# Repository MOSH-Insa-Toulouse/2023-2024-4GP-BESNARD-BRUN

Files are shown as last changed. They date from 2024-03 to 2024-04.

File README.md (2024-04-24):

# 2023-2024 : Capteur low-tech Graphite (Niels Brun &amp; Paul Besnard)

## SOMMAIRE
*** 
  - [Contexte](#contexte)
  - [Livrables](#livrables)
  - [Matériel nécessaire](#matériel-nécessaire)
  - [1. Simulation électronique du capteur sous LTSpice](#simulation-électronique-du-capteur-sous-ltspice)
  - [2. Design du PCB sous KiCad](#design-du-pcb-sous-kicad)
  - [3. Code arduino](#code-arduino)
  - [4. Application android APK sous MIT App Inventor](#application-android-apk-sous-mit-app-inventor)
  - [5. Réalisation du shield](#réalisation-du-shield)
  - [6. Banc de test](#banc-de-test)
  - [7. Datasheet](#datasheet)
  - [Contact](#contact) 

*** 

## Contexte
&nbsp;&nbsp;&nbsp;&nbsp;&nbsp;&nbsp;Dans le cadre de l'UF "Du capteur au banc de test" se déroulant en 4ème année de Génie Physique de l’INSA Toulouse, nous avons développé un dispositif permettant de mesurer la contrainte. Le capteur du dispositif est basé sur l'article "Pencil Drawn Strain Gauges and Chemiresistors on Paper" (Cheng-Wei Lin*, Zhibo Zhao*, Jaemyung Kim & Jiaxing Huang). Il est simplement composé d'un bout de papier avec du graphite que l'on vient déposer à l'aide d'un crayon à papier. En déformant le papier, le nombre de particules de graphite reliées, composant le crayon à papier déposé sur le papier, varie en fonction du type de déformation. Ce système granulaire subit une modification de résistance et de conductance. Grâce à cela, on  pourra remonter à la déformation tel une jauge de contrainte traditionnel. \
&nbsp;&nbsp;&nbsp;&nbsp;&nbsp;&nbsp;L'objectif est donc de pouvoir réaliser un dispositif permettant la mesure de déformation à partir d'un capteur low-tech. En passant par différentes étapes : simulations électroniques, design du PCB, code arduino et réalisation de datasheet.

## Livrables
- Un Shield PCB relié à une carte arduino UNO avec différents composants : un capteur graphite, un amplificateur transimpédance et un module bluetooth. Il peut également avoir un écran OLED, un flex sensor commercial, un potentiomètre digital, encodeur rotatoire ou des boutons.
- Un code arduino qui gère les différents composants cités précédemments (mesures de contraintes, échanges bluetooth et OLED, potentiomètre digital et boutons)
- Une application Android (sous MIT App Inventor) interfaçant le PCB et le code arduino.
- Un code arduino réalisant les essais de banc de test sur les mesures de contraintes.
- Une datasheet sur le capteur de contrainte.

&nbsp;&nbsp;&nbsp;&nbsp;&nbsp;&nbsp;Nous avons opté pour l'ajout d'un écran OLED, du flex sensor commercial, du potentiomètre digital. Egalement, nous avons choisi l'implémentation de 3 boutons plutôt que de l'encodeur rotatoire.

## Matériel nécessaire
Pour réaliser notre dispositif électronique, voici la liste des composants nécessaires :

- Résistances : 1 de 1 $k\ohm$, 1 de $10k\ohm$, 2 de $100k\ohm$ pour l'amplificateur transimpédance. 3 de $10k\ohm$ pour les boutons (peuvent être éviter en utilisant les résistances internes de l'arduino) et 1 de $47k\ohm$ pour le flex sensor.
- Capacités : 3 de 100 nF, 1 de 1 uF
- Arduino Uno
- Amplificateur opérationnel LTC1050
- Potentiomètre digital MCP41050
- Module Bluetooth HC05
- Ecran OLED 128x64
- Flex Sensor
- 3 boutons

## Simulation électronique du capteur sous LTSpice
&nbsp;&nbsp;&nbsp;&nbsp;&nbsp;&nbsp;Notre capteur de graphite possède une résistance variable de l'ordre du gigaohm. Le courant alors généré lorsque l'on applique une tension de 5V aux bornes du capteur est très faible (de l'ordre de la dizaine de nanoampères). Ainsi, pour récupérer et pouvoir analyser ce signal, nous devons l'amplifier. C'est pourquoi nous avons utilisé un montage transimpédance constitué d'un amplificateur opérationnel (AOP) pour fournir un signal en tension suffisant au convertisseur analogique-numérique (ADC) d'une carte Arduino UNO. \
Nous avons testé ce montage sur le logiciel LTspice basé sur [ce schéma](https://github.com/MOSH-Insa-Toulouse/2023-2024-4GP-BESNARD-BRUN/blob/main/Images/LTspice/schema_suggere.png) . Voici son schéma :

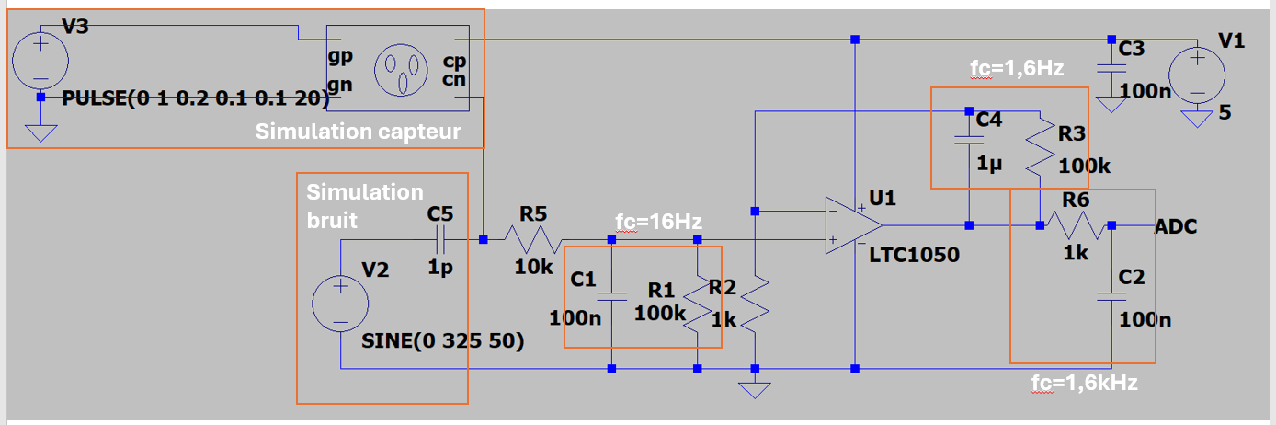
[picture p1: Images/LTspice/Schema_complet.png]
capteur_graphite


&nbsp;&nbsp;&nbsp;&nbsp;&nbsp;&nbsp;Concernant le choix de notre AOP, celui-ci devait être capable d'accepter en entrée un très faible courant. Il doit également avoir un offset de tension très faible afin de ne pas fausser les valeurs de tension transmises à l'ADC qui seront ensuite analysées. C'est pourquoi nous avons choisi le LTC 1050.
A ce circuit amplificateur, nous avons ajouté trois filtres pour notre signal :

- à l'entrée, un filtre passe-bas passif (R1,C1) de fréquence de coupure de 16 Hz. Il permet de filtrer les bruits en courant sur le signal d'entrée
- un autre filtre passe bas de fréquence de coupure de 1.6 Hz (R3,C4) couplé à l'AOP. Ce filtre actif permet de filtrer la composante du bruit à 50 Hz provenant du réseau électrique
- à la sortie de l'amplificateur, un dernier filtre (R6,C2) de 1.6 kHz permet de retirer le bruit créé en cours de traitement (bruits des alimentation, de l'horloge etc...)

&nbsp;&nbsp;&nbsp;&nbsp;&nbsp;&nbsp;Egalement, nous avons placé la capacité C3 de sorte à ce qu'elle filtre le bruit de l'alimentation. Aussi, la résistance R5 en entrée protège l'AOP contre les décharges électrostatiques en plus de formé avec la capacité C1 un filtre pour les bruits en tension. Enfin, la résistance R2 sera remplacé plus tard par un potentiomètre digital. Cela nous permettra de régler le gain de notre AOP en fonction de nos besoins.

Nous avons donc testé notre circuit afin de savoir si nos filtres seraient efficients :

Voici la réponse de notre circuit pour vérfier que le capteur soit correctement amplifié : 

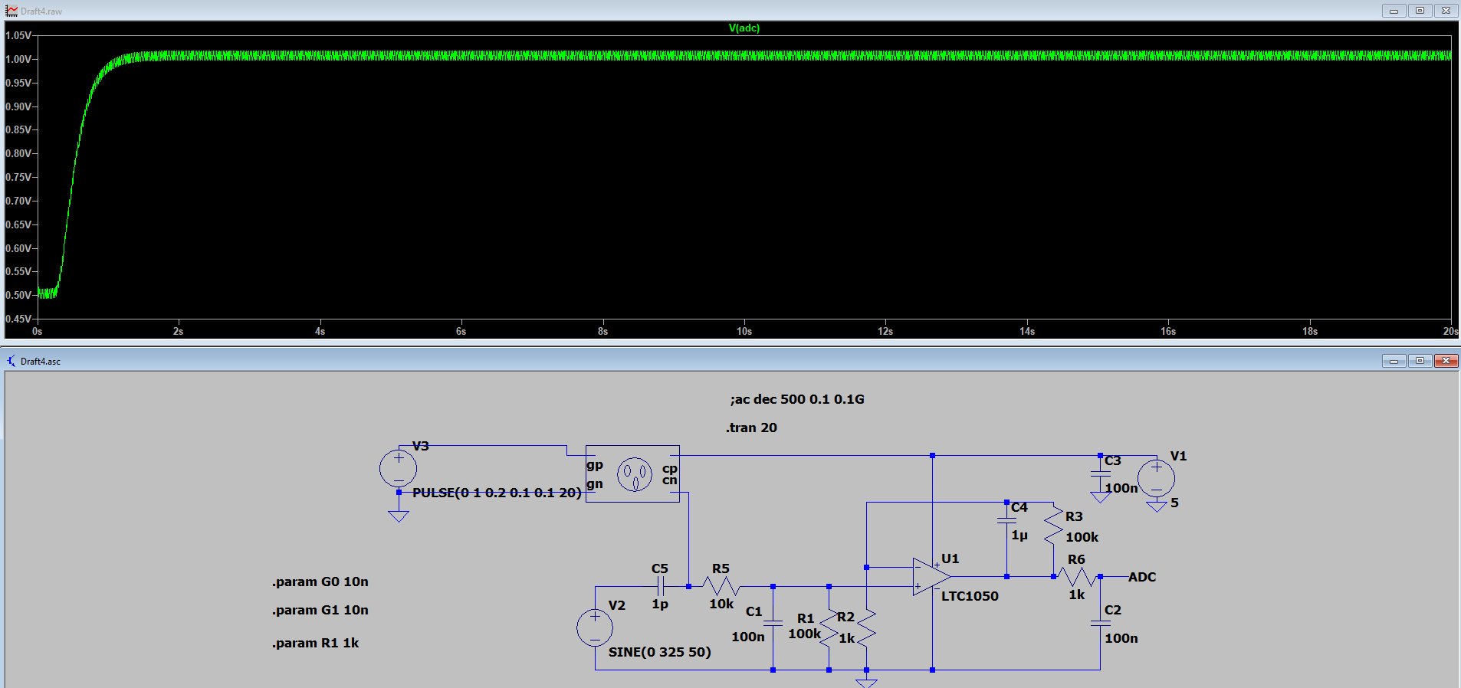
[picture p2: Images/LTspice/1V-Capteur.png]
Test_En_Transient

	
Le signal est amplifié à 1V donc l'arduino UNO pourra le mesurer.

Enfin, voici la réponse lorsque l'on simule un courant alternatif pour vérifier que le bruit est bien filtré.

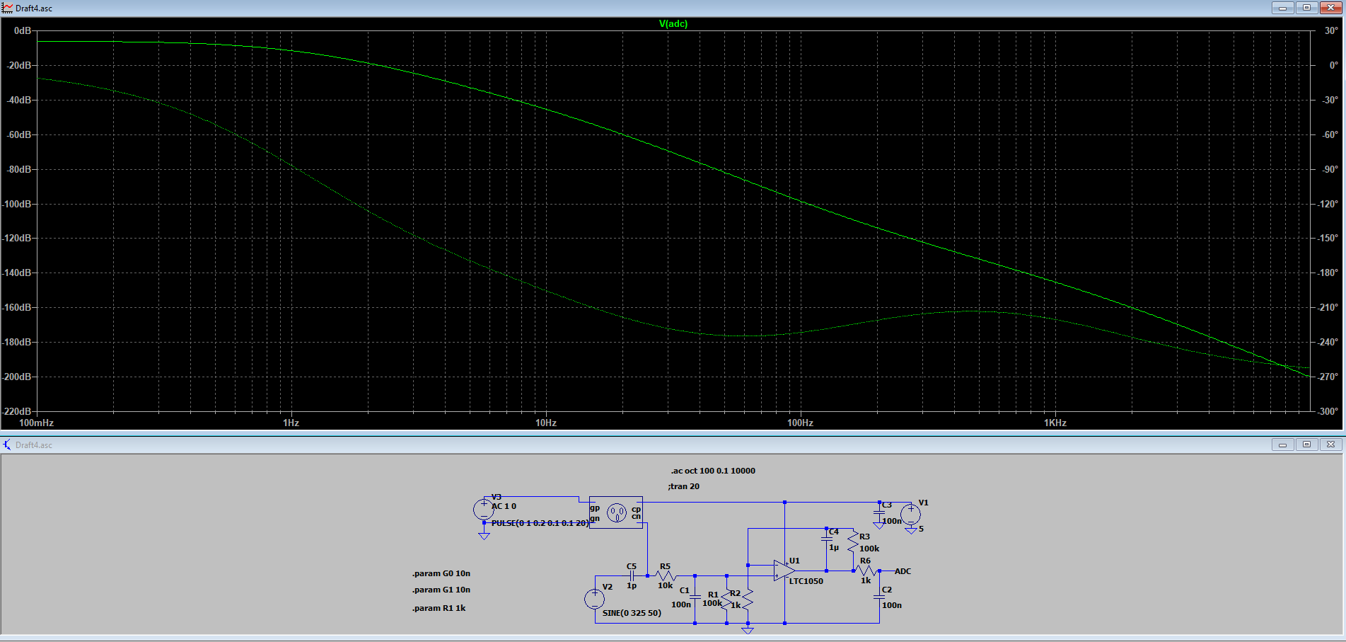
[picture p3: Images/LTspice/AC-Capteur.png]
Test_En_AC


On remarque que le bruit est bien atténué, à 50Hz, il est atténue d'environ 72 dB.

## Design du PCB sous KiCad

&nbsp;&nbsp;&nbsp;&nbsp;&nbsp;&nbsp;Afin de réaliser notre PCB, nous avons reproduit le circuit précédent sur Kicad 7.0. 
Nous avons remplacé la résistance R2 par un potentiomètre numérique afin de pouvoir faire varier le gain de notre AOP. Egalement, nous avons rajouté divers composants afin de pouvoir mesurer efficacement notre capteur graphite et comparé les résultats obtenus :
- un flexsensor servant de témoin, afin de pouvoir comparer nos mesures avec celle du capteur en graphite
- un module bluetooth HC-05 afin de pouvoir communiquer avec notre circuit depuis notre téléphone depuis une application mobile que nous coderons nous-même. 
- un écran OLED ainsi que trois boutons poussoirs afin de pouvoir visualiser le résultats de nos mesures et pouvoir naviguer simplement dans les différents menus permettant diverses mesures

&nbsp;&nbsp;&nbsp;&nbsp;&nbsp;&nbsp;Tous nos composants seront installés sur un shield d'Arduino UNO. 

&nbsp;&nbsp;&nbsp;&nbsp;&nbsp;&nbsp;Nous avons commencé par réaliser les symboles des différents composants et reproduire le schéma électrique complet sur Kicad. Voici le schéma électrique de l'ensemble de notre montage :

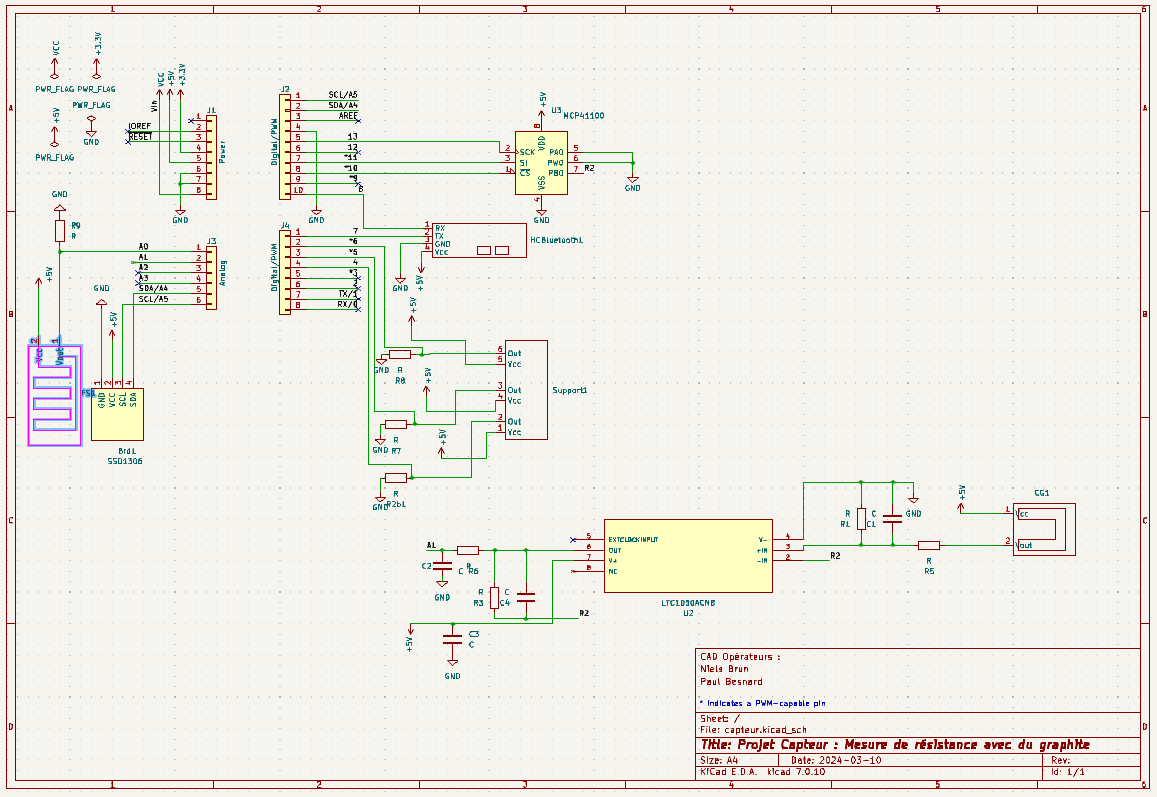
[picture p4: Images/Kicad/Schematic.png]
Schema_Kicad


&nbsp;&nbsp;&nbsp;&nbsp;&nbsp;&nbsp;Nous avons par la suite réalisé les empreintes de nos composants afin de les placer sur notre PCB. Notre difficulté principale a été de placer les composants de sorte qu'il n'y ait pas de via, notamment pour le GND. Voici le résultat final :

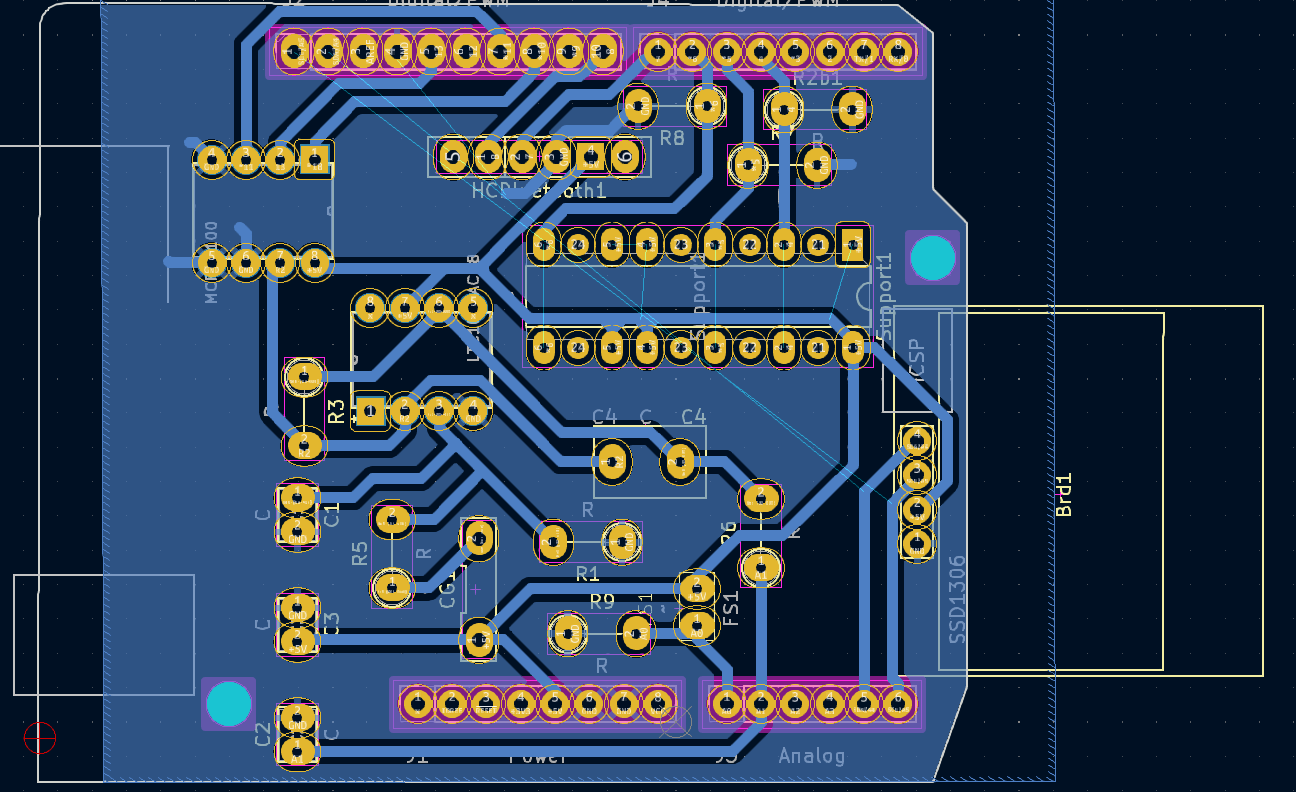
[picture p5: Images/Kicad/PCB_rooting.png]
PCB_Kicad


&nbsp;&nbsp;&nbsp;&nbsp;&nbsp;&nbsp;Et voici le rendu 3D que nous obtenu avec ces routages : 

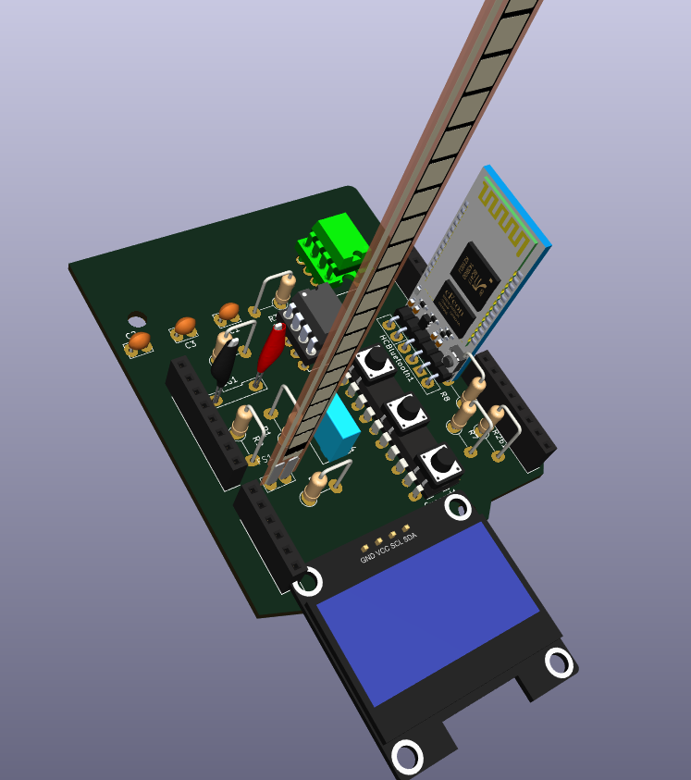
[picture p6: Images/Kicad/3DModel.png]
3D_PCB_Kicad


&nbsp;&nbsp;&nbsp;&nbsp;&nbsp;&nbsp;Toutes les ressources utilisées pour notre Kicad (empreintes, schéma etc...) sont disponibles dans notre [dossier Kicad](https://github.com/MOSH-Insa-Toulouse/2023-2024-4GP-BESNARD-BRUN/tree/main/Kicad).

## Code arduino
&nbsp;&nbsp;&nbsp;&nbsp;&nbsp;&nbsp;Nous avons utilisé l'IDE Arduino 2.3.2. Nous avons utilisé les librairies SoftwareSerial pour le bluetooth et Adafruit_SSD1306 pour l'écran OLED. Sur cette dernière, elle utilise beaucoup de RAM pour les buffers, cette utilisation de RAM n'est pas affiché par l'IDE Arduino. Il se peut que le programme ne se lance pas si une attention n'a pas été porté sur cette utilisation de RAM. Pour éviter cela, on peut utiliser  la fonction ["F()"](https://www.arduino.cc/reference/en/language/variables/utilities/progmem/), utiliser des librairies pour l'écran OLED moins gourmandes ou enfin diminuer la résolution de l'écran.

&nbsp;&nbsp;&nbsp;&nbsp;&nbsp;&nbsp;Dans le [dossier arduino](https://github.com/MOSH-Insa-Toulouse/2023-2024-4GP-BESNARD-BRUN/tree/main/Arduino) se trouve les différents fichiers pour tester les multiples éléments du dispositif. \
Concernant le [fichier principal](https://github.com/MOSH-Insa-Toulouse/2023-2024-4GP-BESNARD-BRUN/blob/main/Arduino/Main/Main.ino) : lors de la mise sous tension de l'arduino, une première calibration du potentiomètre digitale est faite en fonction de la valeur mesurée sur le capteur graphite. 
Suite à cela, le dispositif est par défaut dans le menu déroulant avec 4 choix : 
- une mesure instantannée toutes les 500 ms
- une mesure moyennée sur 2500 ms
- une mesure du flex sensor commercial et enfin 
- une calibration du potentiomètre digital

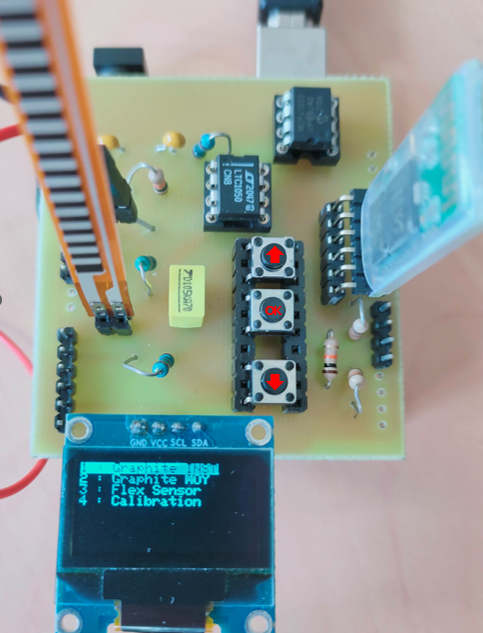
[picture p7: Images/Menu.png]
Menu


&nbsp;&nbsp;&nbsp;&nbsp;&nbsp;&nbsp;Le choix de menu se fait grâce aux 3 boutons : un pour descendre dans le menu, un pour monter dans le menu et un troisième pour valider le choix. Ce dernier bouton de validation sert également à sortir du menu choisi.

&nbsp;&nbsp;&nbsp;&nbsp;&nbsp;&nbsp;Chaque choix du menu appel une fonction différente qui réalise sa mesure et qui est envoyé à la fonction DisplayAndTransmitter afin de l'afficher sur l'écran OLED et l'envoyer sur l'application bluetooth. Tant que le bouton central de "validation" n'est pas appuyé, on reste dans cette boucle de mesure et d'affichage.

&nbsp;&nbsp;&nbsp;&nbsp;&nbsp;&nbsp;Le calcul de la résistance du capteur en graphite se fait avec : $$Res=R1*(1+\frac{R3}{R2})*\frac{Vcc}{Vadc}-R1-R5$$ \
&nbsp;&nbsp;&nbsp;&nbsp;&nbsp;&nbsp;Et dans notre cas, notre résistance R2 est variable : c'est celle du potentiomètre digital qui est calculé avec : $`R2=\frac{47500*pos}{256}+125`$ où notre $47500$ correspond à la valeur de résistance maximale de notre MCP41050 et $pos$ la position du potentiomètre parmi les 256 valeurs.

## Application android APK sous MIT App Inventor
&nbsp;&nbsp;&nbsp;&nbsp;&nbsp;&nbsp;Une application est également disponible avec le dispositif : développé sous [MIT App Inventor](https://appinventor.mit.edu/) . 

&nbsp;&nbsp;&nbsp;&nbsp;&nbsp;&nbsp;L'application reçoit les données transmis par le module bluetooth HC-05. Elle affiche ensuite la valeur tranmis (des $M\ohm$ pour le capteur graphite ou des $\ohm$ pour le flex sensor.

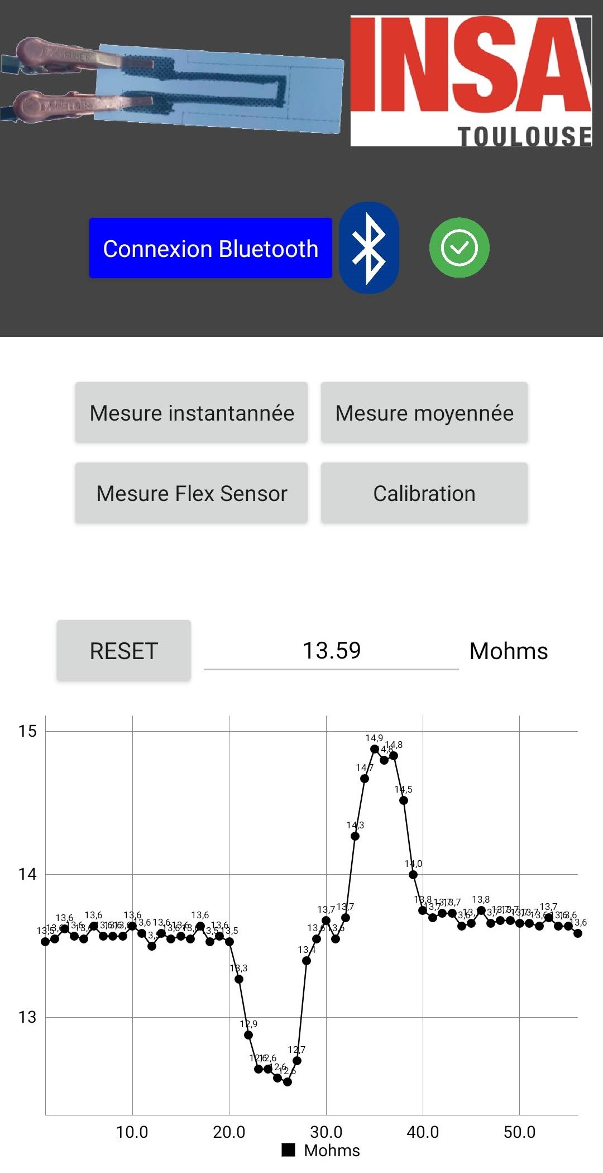
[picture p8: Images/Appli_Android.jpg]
Android


&nbsp;&nbsp;&nbsp;&nbsp;&nbsp;&nbsp;L'application peut s'installer [sous android ici](https://github.com/MOSH-Insa-Toulouse/2023-2024-4GP-BESNARD-BRUN/tree/main/Android/CapteurGraphite.apk) et toutes les informations liées à l'application son dans [le dossier Application Android](https://github.com/MOSH-Insa-Toulouse/2023-2024-4GP-BESNARD-BRUN/tree/main/Android)

## Réalisation du shield

&nbsp;&nbsp;&nbsp;&nbsp;&nbsp;&nbsp;Grâce à notre Kicad, nous avons pu éditer un masque de gravure de notre PCB. Nous avons envoyé notre projet Kicad à Cathy qui s'est chargée de l'imprimer. Elle a ensuite insolé aux UV une plaque d'Epoxy recouverte d'une fine couche de cuivre et d'une résine photosensible. Puis, elle a plongé la plaquette insolée dans du révélateur afin de retirer la résine non insolée, puis dans du perchlorure de fer afin de graver les pistes. Enfin, elle a nettoyé notre plaquette avec de l'acétone afin de retirer la résine restante. Merci beaucoup à Cathy qui a pris le temps de tirer notre PCB et nous expliquer le processus de fabrication!

&nbsp;&nbsp;&nbsp;&nbsp;&nbsp;&nbsp;Nous avons ensuite procéder au perçage de notre plaquette afin de pouvoir installer nos différents composants selon le schéma du PCB obtenu grâce à Kicad. Une fois le perçage terminé, nous avons soudé nos composants à la plaquette.

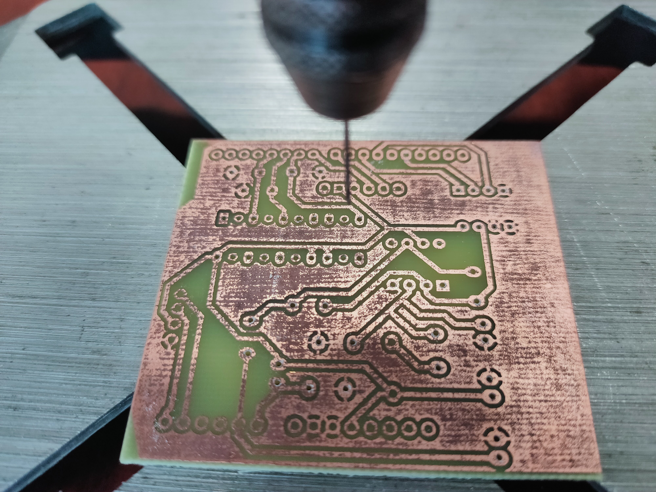
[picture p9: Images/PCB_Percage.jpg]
perçage de notre PCB


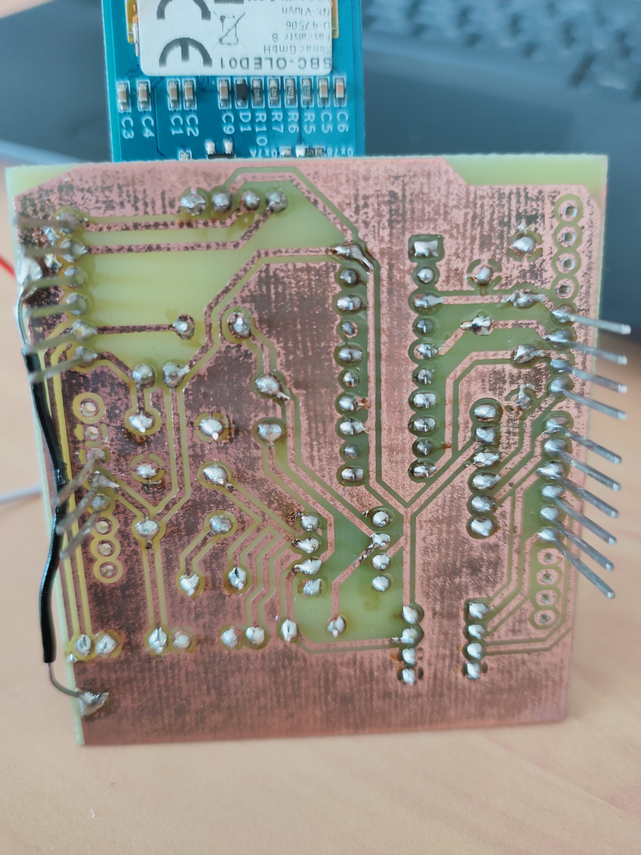
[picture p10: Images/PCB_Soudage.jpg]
soudage de notre PCB


&nbsp;&nbsp;&nbsp;&nbsp;&nbsp;&nbsp;Lors de cette étape, l'installation de nos composants a été plus compliquée que prévue. En effet, l'ensemble de nos trous étaient légèrement décalés par rapport à leur emplacement prévu. L'origine de ce problème n'a pas été clairement établie.

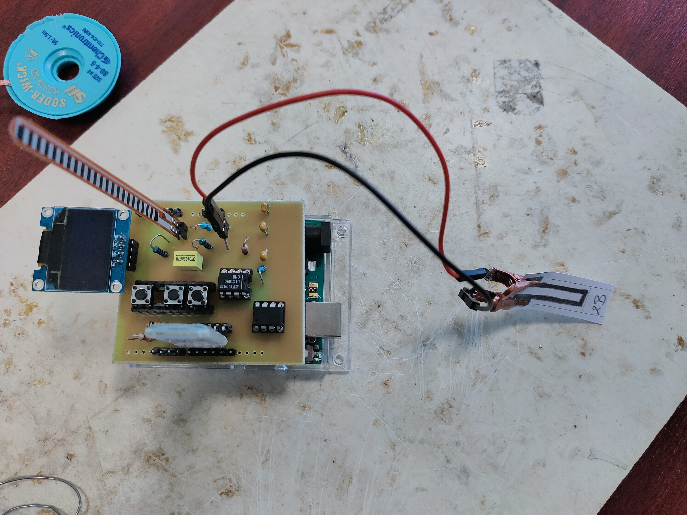
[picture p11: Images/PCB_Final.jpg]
PCB final


## Banc de test

&nbsp;&nbsp;&nbsp;&nbsp;&nbsp;&nbsp;Pour spécifier notre capteur et son montage transimpédance, nous avons décidé d'utiliser des demis-cercles avec un rayon différents.

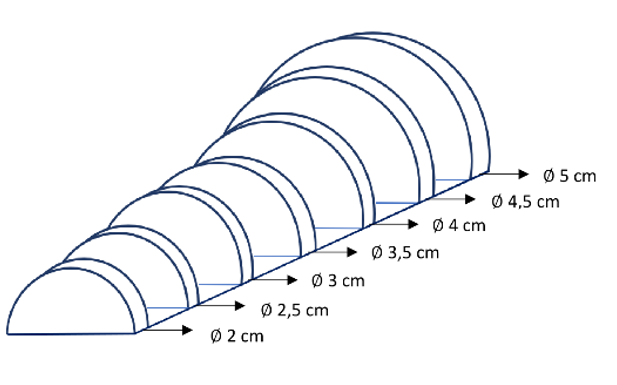
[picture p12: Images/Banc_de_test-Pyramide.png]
Image Banc de Test


&nbsp;&nbsp;&nbsp;&nbsp;&nbsp;&nbsp;Ce sont des demis-cercles, imprimés en 3D, avec un diamètre commençant à 2 cm pour le plus petit et en augmentant de 0.5 cm par créneau. Le plus grand demi-cercle a un diamètre de 5cm. Grâce à ces demis-cercles, nous allons pouvoir calculer la variation de la résistance électrique $\frac{\Delta R}{R_0}$ en fonction de la déformation $\epsilon=\frac{e}{D}$. Nous avons ici mesuré notre épaisseur de notre papier $e=0.2 mm$. Ainsi, nous avons une déformation variant de 0.1 pour le plus petit diamètre à 0.04 pour le plus grand. Voici les courbes caractéristiques pour des crayons 2B, B et HB pour [des tensions ou des compressions.](https://github.com/MOSH-Insa-Toulouse/2023-2024-4GP-BESNARD-BRUN/tree/main/Images/Compression-Tension.png)

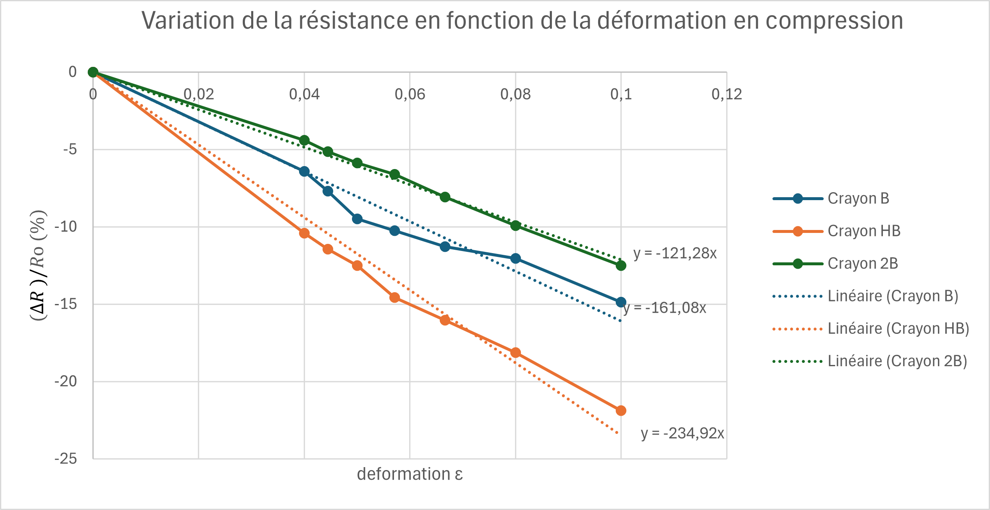
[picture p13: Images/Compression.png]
Compression


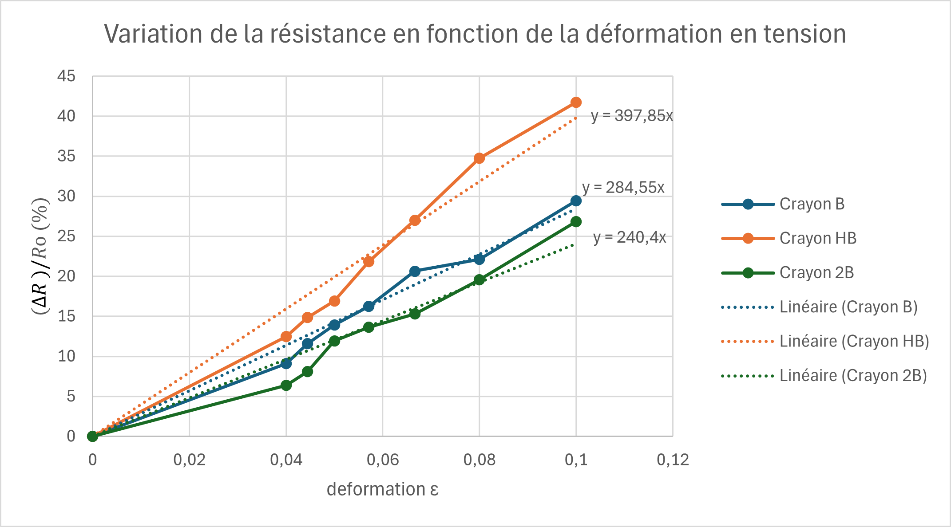
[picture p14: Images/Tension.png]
Tension


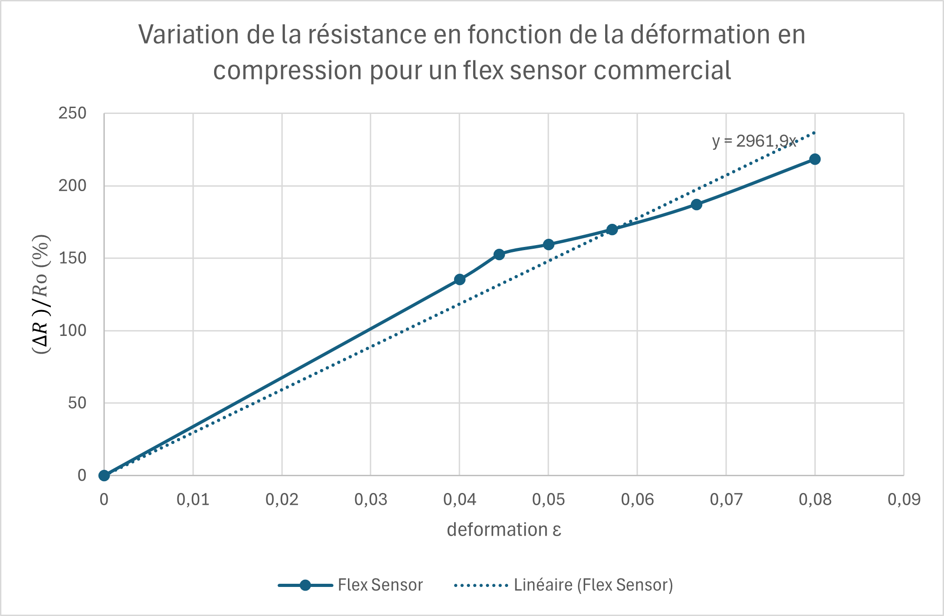
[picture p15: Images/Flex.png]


&nbsp;&nbsp;&nbsp;&nbsp;&nbsp;&nbsp;On remarque que la résistance augmente lorsque l'on met le capteur en tension et qu'elle diminue lors de la compression de ce dernier. En tension, la distance entre les atomes de carbones augmente et la résistance augmente avec. Le contraire se produit pour la compression. \
&nbsp;&nbsp;&nbsp;&nbsp;&nbsp;&nbsp;En fonction de la dureté du crayon utilisé, les variations relatives de résistance changent. Plus le crayon est gras (2H->H->HB->B->2B avec 2B avec le plus de carbone), moins sa variation relative de résistance est élevée.

&nbsp;&nbsp;&nbsp;&nbsp;&nbsp;&nbsp;De plus, contrairement, à l'article "Pencil Drawn Strain Gauges and Chemiresistors on Paper" (Cheng-Wei Lin*, Zhibo Zhao*, Jaemyung Kim & Jiaxing Huang), nous avons pu mesurer la résistance avec un crayon 2H.

&nbsp;&nbsp;&nbsp;&nbsp;&nbsp;&nbsp;Enfin, on peut comparer notre capteur avec un flex sensor commercial. Il semblerait que le flex sensor soit plus sensible à la déformation, en plus d'être plus solide pour des déformations importantes. Pour notre capteur, il a un nombre d'utilisation très limité, qui diminue très fortement pour une déformation élevée.

&nbsp;&nbsp;&nbsp;&nbsp;&nbsp;&nbsp;Néanmoins, toutes ces mesures sont à prendre avec du recul au vu des conditions non reproductibles d'essai. En effet, la quantité de graphite déposée au crayon à papier est très variable, induisant ainsi une résistance très variable. Il serait intéressant de développer une méthode afin de déposer une quantité fixe et reproductible de graphite.
&nbsp;&nbsp;&nbsp;&nbsp;&nbsp;&nbsp;Egalement, nous conseillerons de changer de banc de test et d'utiliser un servo-moteur qui permet de créer des conditions plus reproductibles, que ce soit pour le carbone qui n'est pas déposé sur le banc de test mais également par l'angle imposé qui est précisement connu. Autrement, il faudrait reproduire des cercles de diamètres connues mais avec des déformations moins importantes afin de moins endommager le capteur.

## Datasheet

&nbsp;&nbsp;&nbsp;&nbsp;&nbsp;&nbsp; Vous pouvez retrouver la datasheet du produit [ici](https://github.com/MOSH-Insa-Toulouse/2023-2024-4GP-BESNARD-BRUN/tree/main/datasheet.pdf)

## Contact

&nbsp;&nbsp;&nbsp;&nbsp;&nbsp;&nbsp;Vous pouvez nous contacter pour toutes questions :
- Niels Brun : niels.brun@insa-toulouse.fr
- Paul Besnard : paul.besnard@insa-toulouse.fr

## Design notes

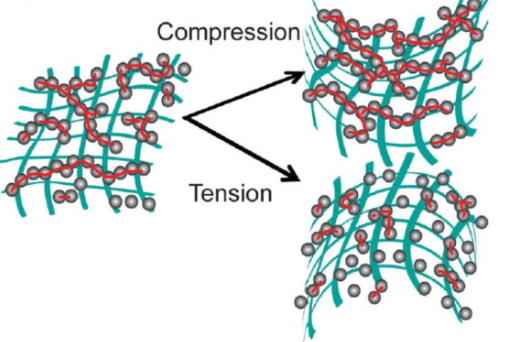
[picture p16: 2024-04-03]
Images/Compression-Tension.png

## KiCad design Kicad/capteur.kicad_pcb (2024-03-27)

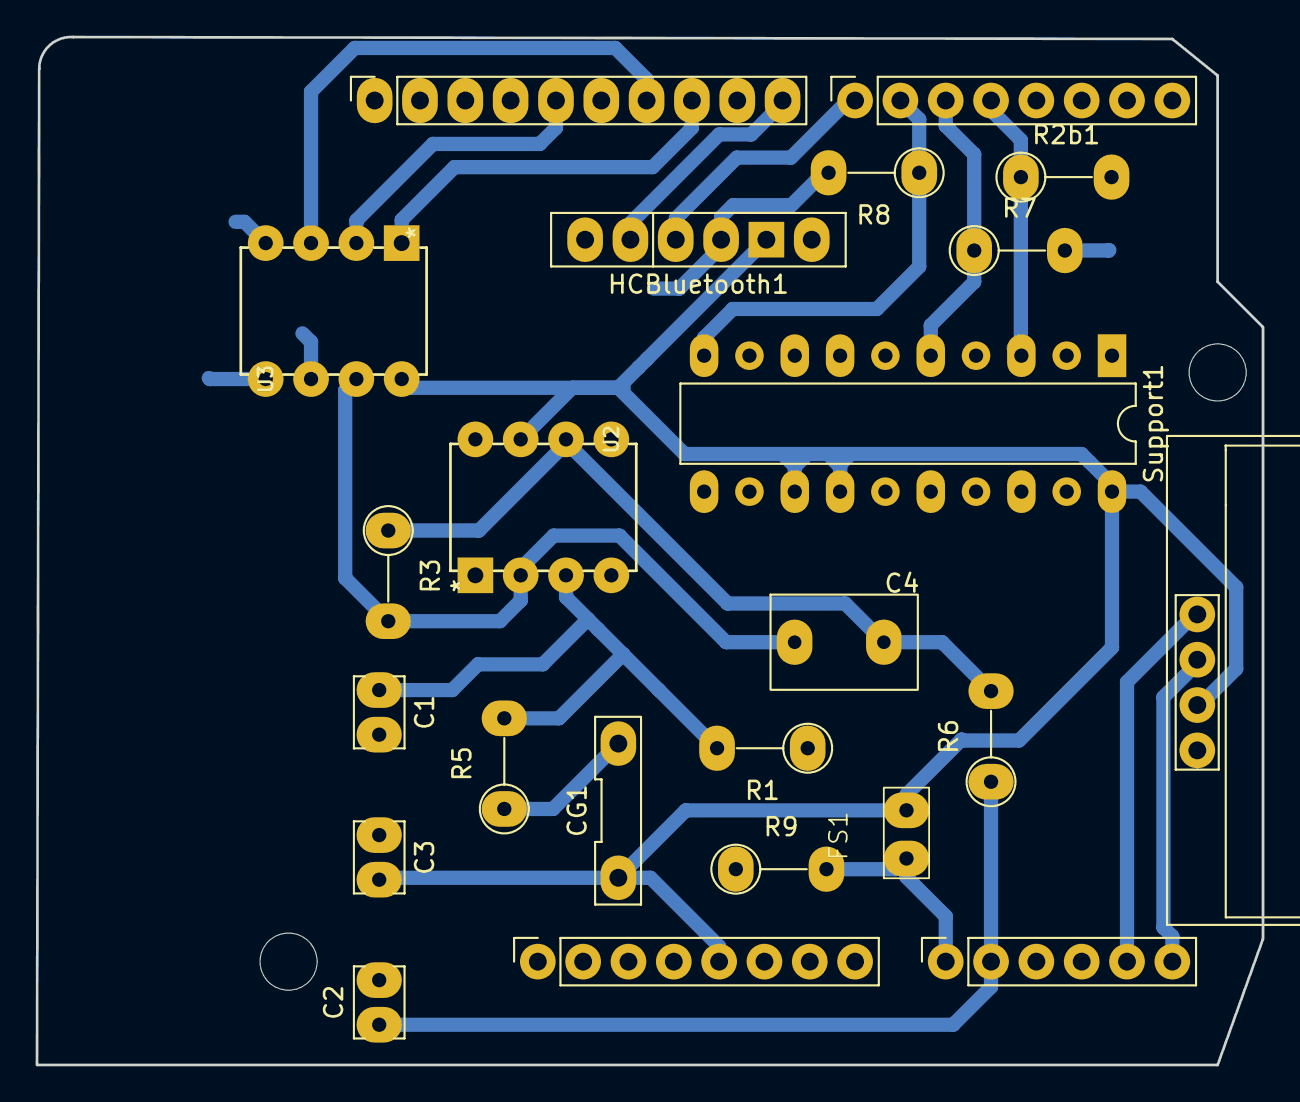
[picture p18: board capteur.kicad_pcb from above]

Board: 2 copper layers, 68.7 x 57.6 mm, 25 parts (0 on the bottom side), 18 nets.

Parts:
Brd1: SSD1306; 128x64OLED
C1, C2, C3: C; capa
C4: C; C4
CG1: CG
FS1: FlexSensor
HCBluetooth1: Bluetooth_HC-05
J1: Power; PinSocket_1x08_P2.54mm_Vertical
J2: Digital/PWM; PinSocket_1x10_P2.54mm_Vertical
J3: Analog; PinSocket_1x06_P2.54mm_Vertical
J4: Digital/PWM; PinSocket_1x08_P2.54mm_Vertical
MH2, MH3: MountingHole_3.2mm
R1, R2b1, R3, R5, R6, R7, R8, R9: R; R_Axial_DIN0207_L6.3mm_D2.5mm_P5.08mm_Vertical
Support1: DIP-20_W7.62mm_LongPads
U2: LTC1050ACN8; LTC
U3: MCP41100; LTC

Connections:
+5V: Brd1.2 (VCC), C3.2, CG1.1 (Vcc), FS1.2 (Vcc), HCBluetooth1.4 (Vcc), J1.5, Support1.1 (Vcc), Support1.4 (Vcc), Support1.5 (Vcc), U2.7 (V+), U3.8 (VDD)
/4: J4.4, R2b1.1, Support1.2 (Out)
/7: HCBluetooth1.2 (TX), J4.1
/8: HCBluetooth1.1 (RX), J2.10
/13: J2.5, U3.2 (SCK)
/*5: J4.3, R7.1, Support1.3 (Out)
/*6: J4.2, R8.1, Support1.6 (Out)
/*10: J2.8, U3.1 (~CS)
/*11: J2.7, U3.3 (SI)
/A0: FS1.1 (Vout), J3.1, R9.2
/A1: C2.1, J3.2, R6.1
/R2: C4.1, R3.2, U2.2 (-IN), U3.7 (PB0)
/SCL/A5: Brd1.3 (SCL), J2.1, J3.6
/SDA/A4: Brd1.4 (SDA), J2.2, J3.5
GND: Brd1.1 (GND), C1.2, C2.2, C3.1, HCBluetooth1.3 (GND), J1.6, J1.7, J2.4, R1.1, R2b1.2, R7.2, R8.2, R9.1, U2.4 (V-), U3.4 (VSS), U3.5 (PA0), U3.6 (PW0)
unnamed: CG1.2 (Vout), R5.1
unnamed: C1.1, R1.2, R5.2, U2.3 (+IN)
unnamed: C4.2, R3.1, R6.2, U2.6 (OUT)

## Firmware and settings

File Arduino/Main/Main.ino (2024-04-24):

//Bluetooth
#include <SoftwareSerial.h>
#define rxPin 7 // Correspondant à la broche tx du module bluetooth
#define txPin 8 // Correspondant à la broche Rx du module bluetooth
#define baudrate 9600 
SoftwareSerial mySerial(rxPin ,txPin); //Definition du software serial

//OLED ATTENTION, la librarie utilisée (d'origine) consomme énormement de mémoire RAM en buffer qui n'est pas affiché sur arduino (possible même si affiché seulement 40%)
// Si le programme ne lance rien, même pas le setup, le problème peut venir de là.
// On peut soit baisser le nombre de pixels dans l'écran, soit utiliser d'autre librairie moins gourmande facilement trouvable sur internet.
#include <Adafruit_SSD1306.h>
#define nombreDePixelsEnLargeur 128        // Taille de l'écran OLED, en pixel, au niveau de sa largeur
#define nombreDePixelsEnHauteur 64        // Taille de l'écran OLED, en pixel, au niveau de sa hauteur
#define brocheResetOLED         -1          // Reset de l'OLED partagé avec l'Arduino (d'où la valeur à -1, et non un numéro de pin)
#define adresseI2CecranOLED     0x3C        // Adresse de "mon" écran OLED sur le bus i2c (généralement égal à 0x3C ou 0x3D)
Adafruit_SSD1306 ecranOLED(nombreDePixelsEnLargeur, nombreDePixelsEnHauteur, &Wire, brocheResetOLED);  

// MESURE Pin pour mesure de la tension du capteur //////////
const int capteurgraphitePin = 1;  // Pin A1
float calibre = pow(10,-6); // pour avoir des Mohms
// Variables pour éviter le delay 
unsigned long previousMillis = 0;        // will store last time LED was updated
// Variable pour cadencer l'acquisition
const long interval = 500;           // interval at which to blink (milliseconds) for MesureINST

// MESURE FLEX SENSOR
const int flexPin = A0;      // Pin connected to voltage divider output
const float VCC = 5;      // voltage at Ardunio 5V line
const float R_DIV = 47000.0;  // resistor used to create a voltage divider
const float flatResistance = 30000.0; // resistance when flat
const float bendResistance = 1000.0;  // resistance at 90 deg

//BOUTONS
const int buttonPin[] = {4,5,6};  // Pin connected to button
// Variables will change:
bool buttonState[3]= {LOW,LOW,LOW};            // the current reading from the input pin
bool lastButtonState[3] = {LOW,LOW,LOW};  // the previous reading from the input pin
bool reading; // variable pour stocker la lecture de l'etat des boutons
//Variable debouncing
unsigned long lastDebounceTime = 0;  // the last time the output pin was toggled
unsigned long debounceDelay = 50;    // the debounce time; increase if the output flickers

// MENU ///////////////////////////
int Position = 1; // Position par défaut dans le menu
int OK = 0;        // Si le bouton central a été appuyé ou pas
String text1="1 : Graphite INST"; // Les différents menus
String text2="2 : Graphite MOY";
String text3="3 : Flex Sensor";
String text4="4 : Calibration";

//Android
bool OK_TEL=0; // Si un bouton sur téléphone a été cliqué.

// Digital Potentiometer
#include <SPI.h>
const byte csPin           = 10;      // MCP42100 chip select pin
const int  maxPositions    = 256;     // wiper can move from 0 to 255 = 256 Positions
const long rAB             = 52200;   // 50k pot resistance between terminals A and B, mais pour ajuster au multimètre, je mets 47500
const byte rWiper          = 125;     // 125 ohms pot wiper resistance
const byte pot0            = 0x11;    // pot0 addr // B 0001 0001
const byte pot0Shutdown    = 0x21;    // pot0 shutdown // B 0010 0001
long R2;                              // Valeur de R2 calculé en sortir du potentiomètre
int PotPos;                           // Valeur de la position du potentiomètre entre 0 et 255

// Permet de gérer le potentiomètre
void setPotWiper(int addr, int pos) {
  pos = constrain(pos, 0, 255);            // limit wiper setting to range of 0 to 255
  digitalWrite(csPin, LOW);                // select chip
  SPI.transfer(addr);                      // configure target pot with wiper Position
  SPI.transfer(pos);
  digitalWrite(csPin, HIGH);               // de-select chip

  R2 = ((rAB * pos) / maxPositions ) + rWiper; // Calcul de R2 (résistance entre wiper et B)
  Serial.print(F(" Resistance wiper to B terminal: "));
  Serial.print(R2);
}


void setup() {
    // Initialisation de l'écran OLED
  if(!ecranOLED.begin(SSD1306_SWITCHCAPVCC, adresseI2CecranOLED))
    while(1);   
  mySerial.begin(baudrate); // Initialiser le port bluetooth
  Serial.begin(baudrate); // Initialiser le port série


  pinMode(buttonPin[0], INPUT);     // Initialise les boutons
  pinMode(buttonPin[1], INPUT);
  pinMode(buttonPin[2], INPUT);
  digitalWrite(csPin, HIGH);        // chip select default to de-selected
  SPI.begin();
  delay(5000);
  PotPos=Calibration();             // Calibration du potentiomètre en fonction du capteur
  // setPotWiper(pot0,int(5));
  // R2=1144;
  }
  
void loop() {
  ChoixMenu(); // Affiche le menu et ses choix en boucle
}

// Permet de se balader dans les 4 menus différents
//MENU 1 : MesureINST : Mesure du capteur graphite toutes les 700ms~~
//MENU 2 : MesureMoyenne : Mesure du capteur graphite en faisant 50 mesures sur 2500ms
//MENU 3 : MesureINST : Mesure du capteur flex sensor
//MENU 4 : Calibration : Calibration du potentiomètre en fonction du capteur
void ChoixMenu(){
  // // MENU
  unsigned long currentMillis = millis ();
  if (currentMillis - previousMillis >= 500) 
  {
    previousMillis = currentMillis;
    ecranOLED.clearDisplay();                                   // Effaçage de l'intégralité du buffer
    ecranOLED.setTextSize(1);                           // Taille du texte
    ecranOLED.setCursor(0, 0);                          // Placement du texte
    ecranOLED.setTextColor(SSD1306_WHITE, SSD1306_BLACK);   // Couleur du texte, et couleur du fond
    //setPotWiper(pot0,7);
    CheckBoutons();   // Fonction primordiale : vérifie si les boutons physiques ne sont pas appuyé et ajuste la variable position, OK et OK_TEL (si un bouton sur tél n'est pas cliqué)
    if(Position==1)                       // Si nous sommes en position 1, affiche le texte correspondant (effet de surbrillance)
    {
      ecranOLED.setTextColor(SSD1306_BLACK, SSD1306_WHITE);
      ecranOLED.println(text1);
      ecranOLED.setTextColor(SSD1306_WHITE, SSD1306_BLACK);
      ecranOLED.println(text2);
      ecranOLED.println(text3);
      ecranOLED.println(text4);
      ecranOLED.display();                            // Transfert le buffer à l'écran
      if(OK_TEL==1) // Si un bouton sur téléphone est cliqué
      {
        OK_TEL=0; // Remet à 0
        MesureINST(); 
      }
      else if(OK==1) // Si le bouton central est cliqué
      {
        OK=0;     // Remet à 0
        MesureINST();
      }
    }
    else if (Position==2)// Si nous sommes en position 2, affiche le texte correspondant (effet de surbrillance)
    {
      ecranOLED.println(text1);
      ecranOLED.setTextColor(SSD1306_BLACK, SSD1306_WHITE);   // Couleur du texte, et couleur du fond
      ecranOLED.println(text2);
      ecranOLED.setTextColor(SSD1306_WHITE, SSD1306_BLACK);   // Couleur du texte, et couleur du fond
      ecranOLED.println(text3);
      ecranOLED.println(text4);
      ecranOLED.display();                            // Transfert le buffer à l'écran
       if(OK_TEL==1)
      {
        OK_TEL=0;
        MesureMoyenne();
      }
      else if(OK==1)
      {
        OK=0;
        MesureMoyenne();
      }
    }
    else if (Position==3)// Si nous sommes en position 3, affiche le texte correspondant (effet de surbrillance)
    {
      ecranOLED.println(text1);
      ecranOLED.println(text2);
      ecranOLED.setTextColor(SSD1306_BLACK, SSD1306_WHITE);
      ecranOLED.println(text3);
      ecranOLED.setTextColor(SSD1306_WHITE, SSD1306_BLACK); 
      ecranOLED.println(text4);
      ecranOLED.display();                            // Transfert le buffer à l'écran
       if(OK_TEL==1)
      {
        OK_TEL=0;
        FlexSensor();
      }
      else if(OK==1)
      {
        OK=0;
        FlexSensor();
      }
    }
    else if (Position==4)// Si nous sommes en position 4, affiche le texte correspondant (effet de surbrillance)
    {
      ecranOLED.println(text1);
      ecranOLED.println(text2);
      ecranOLED.println(text3);
      ecranOLED.setTextColor(SSD1306_BLACK, SSD1306_WHITE); 
      ecranOLED.println(text4);
      ecranOLED.display();
      if(OK_TEL==1)
      {
        OK_TEL=0;
        PotPos=Calibration();
      }
      if(OK==1)
      {
        OK=0;
        PotPos=Calibration();
      }    
    }
  }
}


// Vérifie si un bouton a été appuyé
void CheckBoutons()
{
  for (int i = 0; i < 3; i++) {
    reading = digitalRead(buttonPin[i]);

    // check to see if you just pressed the button
    // (i.e. the input went from LOW to HIGH), and you've waited long enough
    // since the last press to ignore any noise:
    // If the switch changed, due to noise or pressing:
    if (reading != lastButtonState[i]) {
      // reset the debouncing timer
      lastDebounceTime = millis();
    }

    if ((millis() - lastDebounceTime) > debounceDelay) {
      // whatever the reading is at, it's been there for longer than the debounce
      // delay, so take it as the actual current state:
      buttonState[i] = reading;
    }
    // save the reading. Next time through the loop, it'll be the lastButtonState:
    lastButtonState[i] = reading;
  }
  if(buttonState[0]==HIGH && Position < 4){ // Permet de descendre dans les menus sauf si en position 4
    Position++;
    buttonState[0]=LOW;}
  else if(buttonState[0]==HIGH && Position == 4){ // Si en position 4 et que l'utilisateur veut descendre, cela le fait remonter en position 1
    Position=1;
    buttonState[0]=LOW;
  }
  if(buttonState[1]==HIGH){ // si bouton central appuyé, alors cela correspond à une validation
    OK=1;
    buttonState[1]=LOW;
    }
  if(buttonState[2]==HIGH && Position > 1){ // Permet de monter dans les menus sauf si en position 1
    Position--;
    buttonState[2]=LOW;
    }
  else if(buttonState[2]==HIGH && Position == 1){// Si en position 1 et que l'utilisateur veut monter, cela le fait descendre en position 4
    Position=4;
    buttonState[2]=LOW;
  }
    if(mySerial.available()>0){ // Lis ce qui a été envoyé sur le module Bluetooth si nécessaire
    switch (mySerial.read()) {
    case 1: // si arduino reçois le chiffre 1 alors
      Position=1;
      //OK=1;
      OK_TEL=1;
      Serial.println(1);
      break;
    case 2: // si arduino reçois le chiffre 2 alors
      Position=2;
      //OK=1;
      OK_TEL=1;
      Serial.println(2);
      break;
    case 3: // si arduino reçois le chiffre 3 alors
      Position=3;
      //OK=1;
      OK_TEL=1;
      Serial.println(3);
      break;
    case 4: // si arduino reçois le chiffre 4 alors 
      Position=4;
      //OK=1;
      OK_TEL=1;
      Serial.println(4);
      break;
    }                   // wait for a second
  }
}


//Amelioration: faire une fonction de tout ce qui est affichage répété dans les 3 fonctions suivantes
// Permet de mesurer toutes les 500ms la valeur du capteur graphite
void MesureINST()
{
  float R3=100000;
  int Vcc=5;
  float R1=100000;
  int R5=10000;
  float Vadc=0;
  float Res=-1;
  // Affiche l'affichage de mesureINST avant les mesures réelles, comme cela, l'utilisateur peut arreter d'appuyer sur le bouton OK et cela évite de le faire sortir du programme
  ecranOLED.clearDisplay();                                   // Effaçage de l'intégralité du buffer
  ecranOLED.setTextSize(1);                   // Taille des caractères (1:1, puis 2:1, puis 3:1)
  ecranOLED.setCursor(0, 0);
  ecranOLED.setTextColor(SSD1306_WHITE, SSD1306_BLACK);   // Couleur du texte, et couleur du fond
  ecranOLED.println(F("Mesure instantannee : "));
  ecranOLED.display();    
  delay(1000);
  do
  {    
    // MESURE
    unsigned long currentMillis = millis();
    if (currentMillis - previousMillis >= interval) {
      previousMillis = currentMillis;
      Vadc = analogRead(capteurgraphitePin)*5.0/1024.0; // Valeur lu en voltage sortant du capteur
      Res=(R1*(1+R3/R2)*Vcc/Vadc-R1-R5)*calibre; // Calcul de la résistance
      Serial.print("Vadc = ");
      Serial.println(Vadc*1024/5);
      DisplayAndTransmitter(Res,1); // Transmet la donnée à afficher à l'ordi, à l'écran et au bluetooth
      CheckBoutons();
      }
  }while(!(OK == 1 || OK_TEL == 1)); // Tant que le bouton OK n'est pas appuyé, continue
  //Position=1;
  OK=0;
  //OK_TEL=0;
  //Permet de donner l'impression à l'utilisateur qu'il est sorti de l'écran MesureINST
  ecranOLED.clearDisplay();                                   // Effaçage de l'intégralité du buffer
  ecranOLED.setCursor(0, 0);
  ecranOLED.setTextSize(1);                 
  ecranOLED.setTextColor(SSD1306_BLACK, SSD1306_WHITE);   // Couleur du texte, et couleur du fond
  ecranOLED.println(text1);
  ecranOLED.setTextColor(SSD1306_WHITE, SSD1306_BLACK);   // Couleur du texte, et couleur du fond
  ecranOLED.println(text2);
  ecranOLED.println(text3);
  ecranOLED.println(text4);
  ecranOLED.display();    
  delay(1000);
 
} 

//Mesure du capteur graphite sur 50 mesures en 2500ms, forme similaire à MesureINST
void MesureMoyenne(){
  float R3=100000;
  int Vcc=5;
  float R1=100000;
  int R5=10000;
  float Vadc=0;
  float Res=-1;
  ecranOLED.clearDisplay();                                   // Effaçage de l'intégralité du buffer
  ecranOLED.setTextSize(1);                   // Taille des caractères (1:1, puis 2:1, puis 3:1)
  ecranOLED.setCursor(0, 0);
  ecranOLED.setTextColor(SSD1306_WHITE, SSD1306_BLACK);   // Couleur du texte, et couleur du fond
  ecranOLED.println(F("Mesure moyennee :"));
  ecranOLED.display();    
  delay(1000);
  do
  { 
    float moyenne=0;  
    for (int i = 0; i < 50; i++) {
      moyenne=moyenne+analogRead(capteurgraphitePin); 
      CheckBoutons();
      delay(50);
    }
    moyenne=moyenne*5/(50*1024); // Fais la moyenne sur les 50 mesures
    Res=(R1*(1+R3/R2)*Vcc/moyenne-R1-R5)*calibre; // Calcul de la résistance à partir de la valeur lue moyenne, possible de faire la moyenne des résistance calculées
    Res=(R1*(1+R3/R2)*Vcc/Vadc-R1-R5)*calibre; // Calcul de la résistance

    //Serial.print(F("Mesure moyennee :"));
    //Serial.println(Res);
    DisplayAndTransmitter(Res,2); // Transmet la donnée à afficher à l'ordi, à l'écran et au bluetooth
  }while(!(OK == 1 || OK_TEL == 1));
  //Position=2;
  OK=0;
  //OK_TEL=0;
  ecranOLED.clearDisplay();                                   // Effaçage de l'intégralité du buffer
  ecranOLED.setCursor(0, 0);
  ecranOLED.setTextSize(1);                 
  ecranOLED.println(text1);
  ecranOLED.setTextColor(SSD1306_BLACK, SSD1306_WHITE);   // Couleur du texte, et couleur du fond
  ecranOLED.println(text2);
  ecranOLED.setTextColor(SSD1306_WHITE, SSD1306_BLACK);   // Couleur du texte, et couleur du fond
  ecranOLED.println(text3);
  ecranOLED.println(text4);
  ecranOLED.display();    
  delay(1000);
}

// Mesure du flex sensor
void FlexSensor(){
  int ADCflex;
  float Vflex;
  float Rflex;
  ecranOLED.clearDisplay();                                   // Effaçage de l'intégralité du buffer
  ecranOLED.setTextSize(1);                   // Taille des caractères (1:1, puis 2:1, puis 3:1)
  ecranOLED.setCursor(0, 0);
  ecranOLED.setTextColor(SSD1306_WHITE, SSD1306_BLACK);   // Couleur du texte, et couleur du fond
  ecranOLED.println(F("Mesure Flex Sensor:"));
  ecranOLED.display();    
  delay(1000);
  do
  {  
    // Read the ADC, and calculate voltage and resistance from it
    ADCflex = analogRead(flexPin);
    Vflex = ADCflex * VCC / 1024.0;
    Rflex = R_DIV * (VCC / Vflex - 1.0); // Calcul de la résistance du flex
    // Use the calculated resistance to estimate the sensor's bend angle:
    // float angle = map(Rflex, flatResistance, bendResistance, 0, 90.0);
    // Serial.println("Bend: " + String(angle) + " degrees");
    delay(500);
    DisplayAndTransmitter(Rflex,3);
    CheckBoutons();
  }while(!(OK == 1 || OK_TEL == 1));
  //Position=3;
  OK=0;
  //OK_TEL=0;    
  ecranOLED.clearDisplay();                                   // Effaçage de l'intégralité du buffer
  ecranOLED.setCursor(0, 0);
  ecranOLED.setTextSize(1);
  ecranOLED.setTextColor(SSD1306_WHITE, SSD1306_BLACK);   // Couleur du texte, et couleur du fond                 
  ecranOLED.println(text1);
  ecranOLED.println(text2);
  ecranOLED.setTextColor(SSD1306_BLACK, SSD1306_WHITE);
  ecranOLED.println(text3);
  ecranOLED.setTextColor(SSD1306_WHITE, SSD1306_BLACK); 
  ecranOLED.println(text4);
  ecranOLED.display();
  delay(1000);
}

// Transmet la donnée à afficher à l'ordi, à l'écran et au bluetooth
void DisplayAndTransmitter(float VALUE, int choix){
  char ResASCII[10];
  dtostrf(VALUE, 5, 2, ResASCII); //Transforme le float en chaine de caractères
  ecranOLED.clearDisplay();                                   // Effaçage de l'intégralité du buffer
  ecranOLED.setTextSize(1);                   // Taille des caractères (1:1, puis 2:1, puis 3:1)
  ecranOLED.setCursor(0, 0);
  ecranOLED.setTextColor(SSD1306_WHITE, SSD1306_BLACK);   // Couleur du texte, et couleur du fond
  if(choix==1){ecranOLED.println(F("Mesure instantanee :"));}
  else if(choix==2){ecranOLED.println(F("Mesure moyennee :"));}
  else if(choix==3){ecranOLED.println(F("Mesure Flex Sensor :"));dtostrf(VALUE, 5, 0, ResASCII);}
  else if(choix==4){ecranOLED.println(F("Calibration en cours"));}
  ecranOLED.setTextSize(3);                   // Ecris en gros
  ecranOLED.setCursor(0, 30); // Ecris à gauche de l'écran
  ecranOLED.print(ResASCII); // Envoyer sur l'écran la valeur
  mySerial.write(ResASCII); // Envoyer sur le port bluetooth la valeur acquise
  Serial.println(ResASCII); // Afficher sur le port série la valeur de la tension mesuré en bytes
  ecranOLED.display();                            // Transfert le buffer à l'écran
  delay(50);

}

//Calibration basé sur un principe de dichotimie, voir internet. Essaie de se placer au centre de la plage des 1024 valeurs
int Calibration(){
  ecranOLED.clearDisplay();                                   // Effaçage de l'intégralité du buffer
  ecranOLED.setTextSize(1);                   // Taille des caractères (1:1, puis 2:1, puis 3:1)
  ecranOLED.setCursor(0, 0);
  ecranOLED.setTextColor(SSD1306_WHITE, SSD1306_BLACK);   // Couleur du texte, et couleur du fond
  ecranOLED.println(F("Calibration en cours"));
  ecranOLED.display();    
  delay(2000);   
  int Vadc=0;
  int tolerance=40; //Tolerance : 512+-20
  int V_Cible = 512;
  int a = 0;
  int b = 255;
  int ite=0;
  while(abs(Vadc - V_Cible) > tolerance)
  {
    Vadc=0;
    ite++;
    PotPos = (a + b)/2; // Prend le milieu  des 2 valeurs précédentes
    setPotWiper(pot0,int(PotPos));
    for(int i=0;i<3;i++)
    {
      Vadc += analogRead(capteurgraphitePin);
      delay(200);
    }
    Vadc = int(Vadc/3);
    Serial.print(F("Position Pota :"));
    Serial.print(PotPos);
    Serial.print(F(". Valeur lue :"));
    Serial.println(Vadc); // Afficher sur le port série la valeur de la tension mesuré en bytes
    DisplayAndTransmitter(PotPos,4);
    if(Vadc > V_Cible){ // on change le minimum ou le maximum
      a = PotPos;}
    else{
      b = PotPos;}
    if(ite>12){break;}
  }
  Serial.print(F("Finie. Pota en "));
  Serial.println(PotPos); // Afficher sur le port série la valeur de la tension mesuré en bytes
  return PotPos;

}

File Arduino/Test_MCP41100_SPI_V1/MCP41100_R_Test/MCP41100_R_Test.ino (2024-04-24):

/*
   MCP42100 Dual 100K Digital Pot Demo
   Based on examples at https://wiki.dfrobot.com/Dual_Digital_Pot__100K__SKU__DFR0520

   Slowly adjusts pot wipers between min and max (0-255)
   to allow measuring the resistance from the wiper to
   one of the end terminals and to observe the operation of the device.

   Wiper setting is displayed on the serial monitor for confirmation.
   Arduino Uno SPI connections:
   Uno            MCP41100
   ------------------------
   D10           CS  (pin 1)
   D11 (MOSI)    SI  (pin 3)
   D13 (SCK)     SCK (pin 2)
*/

#include <SPI.h>

const byte csPin           = 10;      // MCP42100 chip select pin
const int  maxPositions    = 256;     // wiper can move from 0 to 255 = 256 positions
const long rAB             = 52200;   // 100k pot resistance between terminals A and B, 
                                      // mais pour ajuster au multimètre, je mets 92500
const byte rWiper          = 125;     // 125 ohms pot wiper resistance
const byte pot0            = 0x11;    // pot0 addr // B 0001 0001
const byte pot0Shutdown    = 0x21;    // pot0 shutdown // B 0010 0001

void setPotWiper(int addr, int pos) {
  pos = constrain(pos, 0, 255);            // limit wiper setting to range of 0 to 255
  digitalWrite(csPin, LOW);                // select chip
  SPI.transfer(addr);                      // configure target pot with wiper position
  SPI.transfer(pos);
  digitalWrite(csPin, HIGH);               // de-select chip

  // print pot resistance between wiper and B terminal
  long resistanceWB = ((rAB * pos) / maxPositions ) + rWiper;
  Serial.print("Wiper position: ");
  Serial.print(pos);
  Serial.print(" Resistance wiper to B terminal: ");
  Serial.print(resistanceWB);
  Serial.println(" ohms");
}

void setup() {
  Serial.begin(9600);
  Serial.println("MCP41100 Demo");
  
  digitalWrite(csPin, HIGH);        // chip select default to de-selected
  pinMode(csPin, OUTPUT);           // configure chip select as output
  SPI.begin();
}

void loop() {
  // move pot1 wiper manually to specific positions
  Serial.println("Pot 0 Control ");

  setPotWiper(pot0, 0);                    // minimum resistance
  Serial.println(analogRead(1));
  delay(3000);
  setPotWiper(pot0, 64);// 25% resistance
  Serial.println(analogRead(1));
  delay(3000);
  setPotWiper(pot0, 128); // 50% resistance
  Serial.println(analogRead(1));                 
  delay(3000);
  setPotWiper(pot0, 192);  // 75% resistance
  Serial.println(analogRead(1));                
  delay(3000);
  setPotWiper(pot0, 255);                  // 100% resistance
  Serial.println(analogRead(1));
  delay(3000);

  // move pot0 wiper from min to max in increments of 1 position
  Serial.println("Pot 0 Control ");
  for (int i = 0; i < 256; i++) {
    setPotWiper(pot0, i);
    delay(500);
    Serial.println(analogRead(1));
    delay(1000);
  }
  // move pot0 wiper from max to min in decrements of 1 position
  for (int i = 256; i > 0; i--) {
    setPotWiper(pot0, i);
    Serial.println(analogRead(1));
    delay(1000);
  }
}

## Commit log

2024-03-26 small change of pcb and update of readme
    [capteur.kicad_pcb]
2024-03-27 add of image and minor change for main.ino
    [capteur.kicad_pcb]
2024-03-27 Update README.md
    Kicad + réalisation du shield written!
2024-04-19 Update README.md
    Correction mineure d'erreurs de syntaxe

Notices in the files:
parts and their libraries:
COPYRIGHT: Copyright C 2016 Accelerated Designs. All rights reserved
